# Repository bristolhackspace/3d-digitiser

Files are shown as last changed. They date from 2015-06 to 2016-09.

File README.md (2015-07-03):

# 3D digitiser

Based on a project by [fablab.ruc.dk](http://fablab.ruc.dk/diy-digitizer/)

Initial files were taken from the [dropbox](https://www.dropbox.com/sh/vzl923vihrq4mbn/AABVBuYhJRMiPrHT0Bm9Ow42a?dl=0)

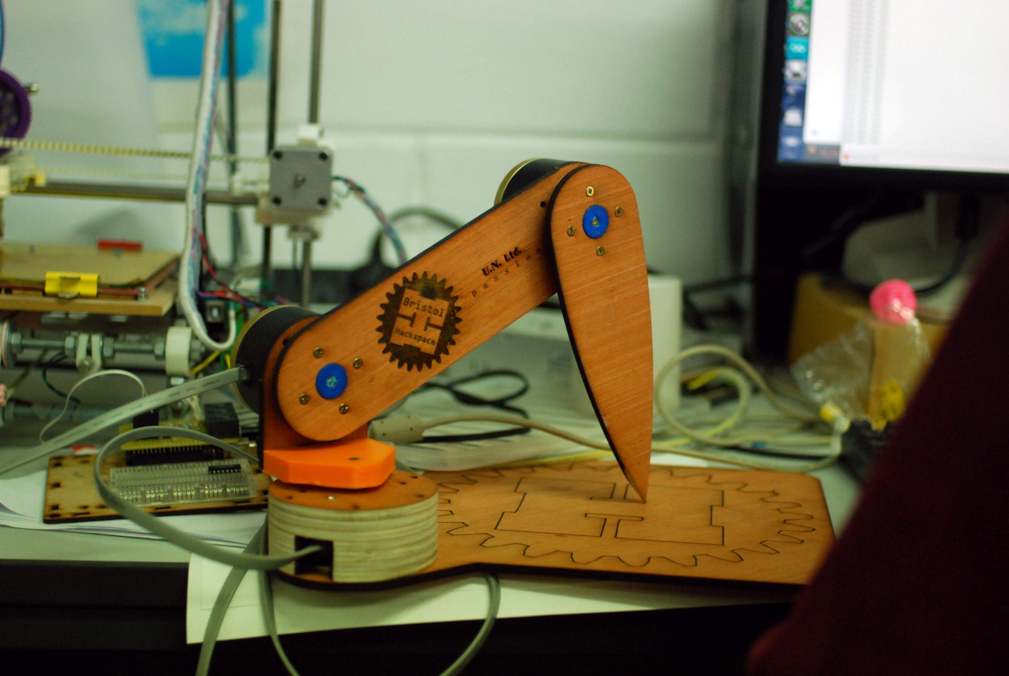
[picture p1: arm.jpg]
arm


# Differences

The main difference was using [USDigital
A2](http://www.usdigital.com/products/a2) encoders, which were a lucky gift.
This changed the CAD (because they are bigger) and the software (because they
communicate over an RS485 bus and are absolute).

# Files

* [laser cut parts](cad/lasercut)
* [3d printed parts](cad/3dprint)
* [PCB](electronics)
* [Arduino code](software/arduino)
* [Processing code](software/processing)

# Licenses

* Hardware is licensed under the [CERN open hardware license 1.2](http://www.ohwr.org/attachments/2388/cern_ohl_v_1_2.txt)

* Software is licensed under a Creative Commons Attribution 4.0 International License.

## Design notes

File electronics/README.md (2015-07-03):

# arduino shield for the usdigital encoders

* provides RS485 differential lines for busy and data.
* provides 12v power to the encoders
* 6 pin GPIO breakout with power and ground
* 2 pin button breakout
* single sided PCB for easy etching

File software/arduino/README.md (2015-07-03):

# software for the arduino

We used very nice [USDigital
A2](http://www.usdigital.com/products/a2) encoders, which were a lucky gift.

They had the best documentation I've probably ever used for a product;
including:

* [comms
 protocol](http://www.usdigital.com/support/user-guides/sei-absolute-encoder-communications-protocol)
* [bus
 specification](http://www.usdigital.com/support/user-guides/sei-serial-encoder-interface-bus)

Matt still needed a scope to get more than 2 working on a bus!

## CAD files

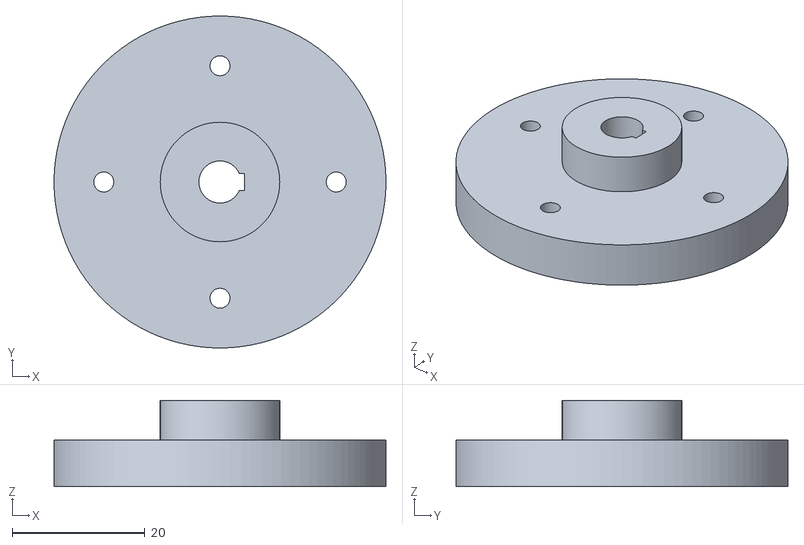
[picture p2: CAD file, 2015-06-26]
cad/3dprint/hub.stl
50.0 x 50.0 x 13.0

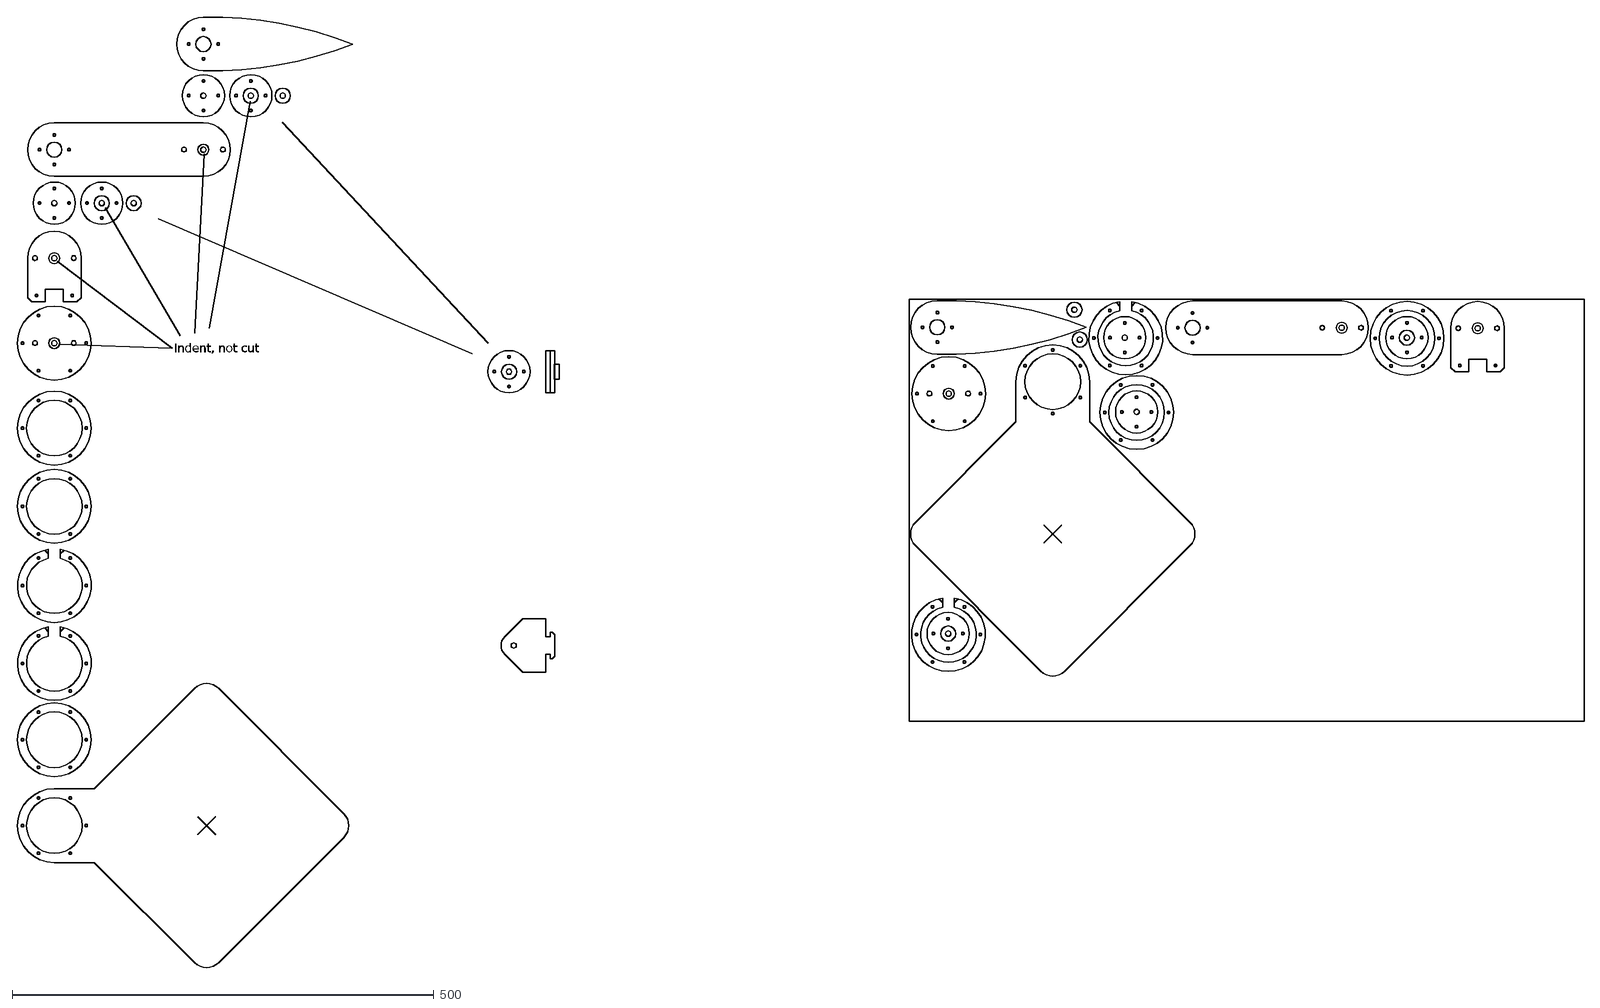
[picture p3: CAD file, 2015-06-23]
cad/lasercut/Digitiser.dxf
Indent, not cut

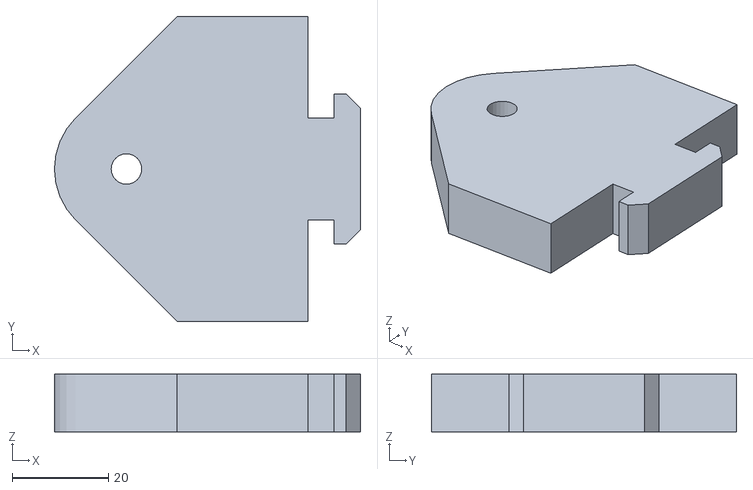
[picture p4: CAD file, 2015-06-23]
cad/3dprint/3d printed part.stl
63.8 x 63.5 x 12.0

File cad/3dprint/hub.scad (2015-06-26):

/* SETTINGS*/
$fn=100;
hstep1 = 7; // base height
hstep2 = 6; // protrusion height
id = 6.34; // inner dia (encoder shaft dia)
od = 18; // outer dia (laser cutting cutout)
radius = 25; // base radius
hradius = 38; // radius about which mouting holes sit
screw = 3; // mouting screw size
intf = 0; // interference fit reduction
// keyway
keyway = true; // add keyway
keywidth = 2.5; // keyway width
keydepth = 1; // keyway depth
/*=============================*/

/* WORKING*/
iid = id - intf; // tolerance fit inner dia

union() {
  base();
  translate([0,0,hstep1]) shaft();
}

module base() {
  difference() {
    cylinder(r=radius, h=hstep1);
    cylinder(r=iid/2, h=hstep1);
    if (keyway) {
      translate([iid/2-keydepth/2,-keywidth/2,0]) cube([keydepth,keywidth,hstep1]);
    }
    holes(hradius);
    rotate(90) holes(hradius);
  }
}

module holes(radius) {
  translate([-radius/2+screw/2,0,0]) cylinder(r=screw/2,h=hstep1);
  translate([radius/2-screw/2,0,0]) cylinder(r=screw/2,h=hstep1);
}

module shaft() {
  difference() {
    cylinder(r=od/2,h=hstep2);
    cylinder(r=iid/2,h=hstep2);
    if (keyway) {
      translate([iid/2-keydepth/2,-keywidth/2,0]) cube([keydepth,keywidth,hstep2]);
    }
  }
}

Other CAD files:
cad/3dprint/3d printed part.dwg
cad/lasercut/Digitiser.dwg

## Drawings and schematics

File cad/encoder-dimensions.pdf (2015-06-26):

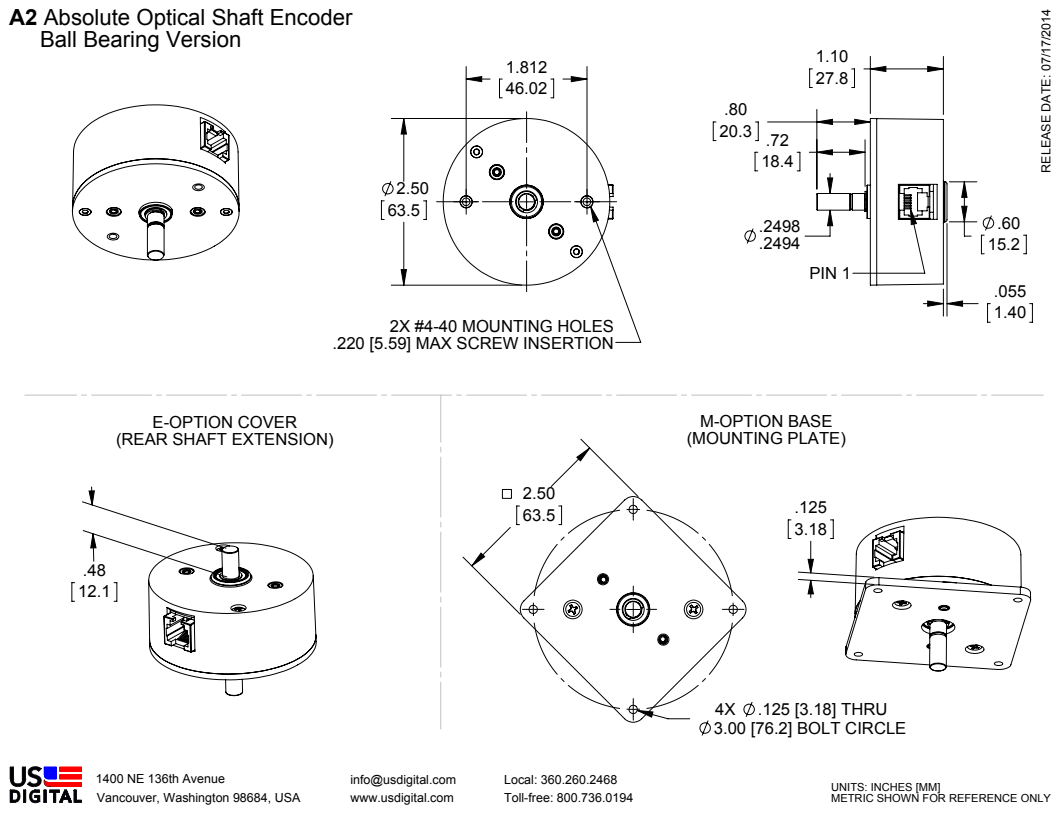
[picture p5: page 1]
Vancouver, Washington 98684, USA; www.usdigital.com; Toll-free: 800.736.0194; 1400 NE 136th Avenue; info@usdigital.com; Local: 360.260.2468; PIN 1; 4X .125 [3.18] THRU 3.00 [76.2] BOLT CIRCLE; M-OPTION BASE (MOUNTING PLATE)

A2 Absolute Optical Shaft Encoder
Ball Bearing Version

METRIC SHOWN FOR REFERENCE ONLYRELEASE DATE: 07/17/2014

2X #4-40 MOUNTING HOLES
.220 [5.59] MAX SCREW INSERTION

E-OPTION COVER
(REAR SHAFT EXTENSION)

UNITS: INCHES [MM]

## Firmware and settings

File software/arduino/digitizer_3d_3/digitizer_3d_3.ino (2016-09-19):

#include "a2abs.h"

//stupidly wasted 2 other gpios by connecting them to serial rx&tx
#define GPIO1 0
#define LED 2
#define GPIO3 3
#define BUTTON 5

//this could be done by telling the encoders where they are is 0, but
//I wanted to avoid more usdigital routines
//array of encoder steps
long encoder_init_step[3]={0,0,0};
//what the encoders are at startup (arm touching centre point)
float encoder_init_angle[3]={0,0,0};

//these are angles
double A; //end pivot = encoder 0
double B; //mid pivot = encoder 1
double C; //base pivot = encoder 2

//steps per encoder
#define STEPS 2048.0

//length of both arm sections
#define ARM_E 173.5 // from cad
#define ARM_M 176.8 // from cad

//height of first pivot from top of base to centre of encoder 1 pivot
#define H0 87.4 // measured
// distance from centre of base to first pivot centre - from cad
#define R0 180.0 //from cad
//base width
#define BW 250.0

double get_angle(int encoder_num);
void sendFloat(float f,unsigned t);
void init_angles();
float cosine_law(float a, float b, float c);

void setup()
{
  setup_a2();
  Serial.begin(115200);
  //init angles
  init_angles();

  //store steps of encoders at startup (as they are absolute)
  encoder_init_step[0]=get_pos(0);
  encoder_init_step[1]=get_pos(1);
  encoder_init_step[2]=get_pos(2);

  pinMode(BUTTON, INPUT);
  digitalWrite(BUTTON, HIGH);
  pinMode(LED, OUTPUT);
  digitalWrite(LED, HIGH);
  
}

void loop()
{
    double A=get_angle(0); //end
    double B=get_angle(1); //mid
    double C=get_angle(2); //base

    // kinematics: http://es.mathworks.com/help/fuzzy/examples/modeling-inverse-kinematics-in-a-robotic-arm.html
    double r=cos(B)*ARM_M+cos(A+B)*ARM_E;
    double h=sin(B)*ARM_M+sin(A+B)*ARM_E+H0;

    double y = BW/2 - r*cos(C);
    double x = BW/2 - r*sin(C);
    double z = h;

    if(Serial.available())
    {
        if(Serial.read() == 'a')
        {
            digitalWrite(LED, HIGH);

            sendFloat(A,'a');
            sendFloat(B,'b');
            sendFloat(C,'c');

            sendFloat(x,'x');
            sendFloat(y,'y');
            sendFloat(z,'z');
            sendFloat(!digitalRead(BUTTON),'B');
            digitalWrite(LED, LOW);
        }
        Serial.flush();
    }
}

//send an identifier & a float via serial
void sendFloat(float f,unsigned t) {
  byte * b = (byte *) &f;
  Serial.write(t);
  Serial.write(b[0]);
  Serial.write(b[1]);
  Serial.write(b[2]);
  Serial.write(b[3]);
}

/* 
returns encoder's angle
compares current steps to starting steps & angle
*/
double get_angle(int encoder_num)
{
    int pos = get_pos(encoder_num);
    int diff = encoder_init_step[encoder_num] - pos;
    double angle = encoder_init_angle[encoder_num] - diff * (2 * M_PI / STEPS);
    return angle;
}

/*
inverse kinematics - only do at startup
calculate all angles in RADIANS when the arm is touched down in centre

If arm was straight horizontal, both joint 0 and joint 1 would be 0. 

A positive lift in either joint will increase the angle

encoder_init_angles has 3 floats:
    0 end
    1 mid
    2 base
*/
void init_angles()
{
    // hypotenuse needed to calc 3rd side of triangle
    float hyp = sqrt(H0*H0 + R0*R0);

    // end angle
    float C = cosine_law(ARM_E, ARM_M, hyp);
    encoder_init_angle[0]=M_PI + C;

    // mid angle
    C = cosine_law(ARM_M, hyp, ARM_E);
    float gamma = atan(H0/R0);
    encoder_init_angle[1] = C - gamma;

    // base angle
    encoder_init_angle[2] = M_PI / 4;
/*
    Serial.println(encoder_init_angle[0]);
    Serial.println(encoder_init_angle[1]);
    Serial.println(encoder_init_angle[2]);
*/
}

float cosine_law(float a, float b, float c)
{
   return acos((a*a + b*b - c*c) / (2*a*b));
}

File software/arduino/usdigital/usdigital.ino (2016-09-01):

/*
http://www.usdigital.com/support/user-guides/sei-absolute-encoder-communications-protocol

http://www.usdigital.com/support/user-guides/sei-serial-encoder-interface-bus

electrical timing:
http://cdn.usdigital.com/assets/general/SEI_Data_Sheet.pdf
*/
#include <SoftwareSerial.h>

SoftwareSerial mySerial(8,9); // RX, TX
#define BUSY 7 //active low
#define DATA_DE 6 //active high

//stupidly wasted 2 other gpios by connecting them to serial rx&tx
#define GPIO1 0
#define GPIO2 1
#define LED 2
#define GPIO3 3
#define BUTTON 5

unsigned int get_pos(byte address);


void setup()
{
  pinMode(LED, OUTPUT);
  pinMode(DATA_DE, OUTPUT);
  pinMode(BUSY,INPUT);
  // set the data rate for the SoftwareSerial port
  mySerial.begin(9600);
  Serial.begin(9600);
  Serial.println("started");
}

void loop() // run over and over
{
	/*
	// set an address
	byte * serial = get_serial();
	Serial.print("address=");
	Serial.println(get_address(serial));
	set_address(0, serial);
	delay(100);
	return;
	*/

	//read all the numbers out
	digitalWrite(LED,HIGH);
	char buf[20];
	sprintf(buf, "%04d,%04d,%04d", get_pos(0), get_pos(1), get_pos(2));
	Serial.println(buf);
	digitalWrite(LED,LOW);
	delay(100);
}

//single byte command
unsigned int get_pos(byte address)
{
	digitalWrite(DATA_DE,HIGH);
	//read position, with no status bytes
 	mySerial.write(0x01 << 4 | address);
	digitalWrite(DATA_DE,LOW);
	delay(1);
	if( ! digitalRead(BUSY))
	{
		Serial.println("no busy"); return -1;
	}

	//2 bytes, significant byte first
	while(mySerial.available()!=2);
	unsigned int pos = mySerial.read() << 8 | mySerial.read();

	//wait for encoder to stop talking
	while(digitalRead(BUSY));

	return pos;
}

/*
Get Address:
6 bytes: request byte, 06, 4 bytes serial number.
Returns 2 bytes: 1 byte serial and checksum if command is successful, only if serial number matches.
The encoder compares its serial number with the one supplied; if they match, it returns its serial (0 to E). Otherwise, it returns nothing.
*/
byte get_address(byte * serial)
{
	digitalWrite(DATA_DE,HIGH);
	mySerial.write(0xFF);
	delay(10);
	if( ! digitalRead(BUSY))
	{
		Serial.println("no busy"); 
		return -1;
	}

	mySerial.write(0x06);
	//serial
	for(int i = 0; i < 4; i ++)
	{
		mySerial.write(serial[i]);
	}
	digitalWrite(DATA_DE,LOW);
	//wait for device to release busy
	while(digitalRead(BUSY));

	byte address = mySerial.read();
	//skip checksum
	mySerial.read();
	//Serial.println(address);
	return address;

}

/*
Read Serial Number:
2 bytes: request byte, 03
Returns 5 bytes: 4 bytes serial number and checksum if command is successful.
*/
byte * get_serial()
{
	static byte serial[4];
	mySerial.flush();

	digitalWrite(DATA_DE,HIGH);
	mySerial.write(0xFF);
	delay(1);
	if( ! digitalRead(BUSY))
	{
	Serial.println("no busy"); return 0;
	}

	mySerial.write(0x03);
	digitalWrite(DATA_DE,LOW);
	//wait for device to release busy
	while(digitalRead(BUSY));
	serial[0] = mySerial.read();
	serial[1] = mySerial.read();
	serial[2] = mySerial.read();
	serial[3] = mySerial.read();
	//checksum byte
	mySerial.read();

	Serial.print("serial=");
	for(int i = 0; i < 4; i ++)
	{
		Serial.print(serial[i]);
		Serial.print(",");
	}
	Serial.println("");
	return serial;

}

/*
Assign Address:
7 bytes: request byte, 07, 4 bytes serial number, 1 byte address.
Returns checksum if command is successful.
The encoder compares its serial number with the one supplied; if they match, it assigns itself the address supplied (must be between 0 and E). The new address is stored in EEPROM, therefore, it will be effective after resets and power downs
*/
void set_address(byte address, byte * serial)
{
	digitalWrite(DATA_DE,HIGH);
	mySerial.write(0xFF);
	delay(1);
	if( ! digitalRead(BUSY))
	{
		Serial.println("no busy");
		return;
	}
	mySerial.write(0x07);
	//serial
	for(int i = 0; i < 4; i ++)
	{
		mySerial.write(serial[i]);
	}
	mySerial.write(address);
	digitalWrite(DATA_DE,LOW);
	//wait for device to release busy
	while(digitalRead(BUSY));
	//skip checksum
	mySerial.read();
}

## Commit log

2015-06-23 Added OpenSCAD hub 3d print part and Nic's laser cutting designs
    [3d printed part.dwg, 3d printed part.stl, Digitiser.dwg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]
2015-06-23 Moved the mounting holes to match Nic's design. Added STL export
    [hub.scad, hub.stl]
2015-06-26 working code for the usdigital encoders
2015-06-26 Updated height of hub for our build
    [hub.scad, hub.stl]
2015-06-26 v1 shield
    [digitiser.brd, digitiser.sch]
2015-06-26 added Rs, double check polarity
    [digitiser.sch]
2015-07-02 arduino moved it on opening
2016-09-08 added python3 support and button
2016-09-19 correct order of initial angles
    [digitizer_3d_3.ino]
